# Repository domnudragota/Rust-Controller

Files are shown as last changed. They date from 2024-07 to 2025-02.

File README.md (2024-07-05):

# Project Name
GamePad/Controller
## Description

Simple GamePad built on a breadboard to test in games. Is built on Windows XInput API, so it will detect it as an XBOX Controller. The purpose of this project is (besides building a controller) to test input latency in different games and on different systems, computers and monitors in order to see the difference in input latency. Will also compare with an actual Xbox Series controller.

## Hardware

<!-- Fill out this table with all the hardware components that you mght need.

The format is 
```
| [Device](link://to/device) | This is used ... | [price](link://to/store) |

```

-->

| Device | Usage | Price |
|---|---|---|
| [Rapspberry Pi Pico W](https://www.raspberrypi.com/documentation/microcontrollers/raspberry-pi-pico.html) | The microcontroller | [35 RON](https://www.optimusdigital.ro/en/raspberry-pi-boards/12394-raspberry-pi-pico-w.html) |
| BreadBoard | Build the circuit | [10 RON] https://www.optimusdigital.ro/ro/prototipare-breadboard-uri/8-breadboard-830-points.html |
| Buttons ( 12-15 ) | Input for controller | [5 RON] https://www.optimusdigital.ro/ro/butoane-i-comutatoare/1119-buton-6x6x6.html?search_query=buton&results=222 |
| Resistances | To not fry the circuit | [5 RON] https://www.optimusdigital.ro/ro/componente-electronice-rezistoare/858-rezistor-025w-18k.html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 |
| 2x JoySticks | Move and aim with the controller | [10 RON] https://www.optimusdigital.ro/ro/senzori-senzori-de-atingere/742-modul-joystick-ps2-biaxial-negru-cu-5-pini.html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 |

## Links

<!-- Add a few links that got you the idea and that you think you will use for your project -->

1. [link](https://learn.microsoft.com/en-us/windows/win32/xinput/getting-started-with-xinput)
2. [link](https://www.howtogeek.com/792984/directinput-vs.-xinput-for-game-controllers-whats-the-difference/)
...

# Software and Code

### Rust Code for Raspberry Pi Pico W
The Rust code deployed on the Raspberry Pi Pico W reads button presses and joystick movements, packaging them into a structured format to be sent over UDP.

## Run the code
* Open the lab-main-Copy-Copy file in which IDE you desire (I used RustRover for this project)
* The code is located in /lab08/lab08_ex3_4/src/main.rs

⚠️ **Warning:** Ensure change the IP adresses and the path target to the cyw43-firmware in the code before you build it. Also the ID and the password of the network. Make sure the band of the network is 2.4GHZ!

```rust
let fw = include_bytes!("C:/Users/Andrei/Desktop/lab-main/cyw43-firmware/43439A0.bin");
let clm = include_bytes!("C:/Users/Andrei/Desktop/lab-main/cyw43-firmware/43439A0_clm.bin");

```

```rust
//change the ip adress as well

match socket
            .send_to(
                &packet,
                //here
                IpEndpoint::new(IpAddress::v4(192, 555, 553, 555), 1234), 
            )
            .await
        {
            Ok(()) => {
                info!("sent")
            }
            Err(e) => {
                warn!("send error: {:?}", e);
            }
        }
        info!("Sending packet to UDP server...");

        //match for joystick
        match socket.send_to(&packet, IpEndpoint::new
        //and here
        (IpAddress::v4(192, 555, 555, 555), 1234)).await {
            Ok(()) => info!("Joystick data sent"),
            Err(e) => warn!("send error: {:?}", e),
         }

    }
```
```rust
//change the network

const WIFI_NETWORK: &str = "da";
const WIFI_PASSWORD: &str = "da";
```

## Building the code
* Open a terminal and make sure you are in the correct directory 

⚠️ **Warning:** Please double check if the terminal correctly detects the directory (including the -Copy - Copy sufixes of the name), otherwise it won't build correctly

* To make sure you are in the correct file, use these commands

```
cd '.\lab-main - Copy - Copy\lab08\lab08_ex3_4\
```
* To build the project, simply type in the terminal
```
cargo build --release --target=thumbv6m-none-eabi  
```
* When it compiles, we need to open an UDP server so that we can send the data.
* Open the _udpserver_ file as a **separate** project/tab.
* Run the server with _cargo run_
* Once the server is fully loaded, go back to the 1st project and type in the terminal in order to flash it on the Pico

```
elf2uf2-rs -d -s ..\..\target\thumbv6m-none-eabi\release\lab08_ex3_4

```
* When the Pico connects to the UDP server, it will constantly send packets to the server
* Now we need a "translator" to decode the packets

# Detecting the Controller on Windows

## Prerequisites

Before you begin setting up the project, ensure you have the following prerequisites installed on your system:

## System Requirements
- **Operating System**: Windows 10 or newer is recommended for full compatibility.

## Software Requirements
- **.NET Framework**: .NET 5.0 or later. Make sure to download and install it from [Microsoft's official site](https://dotnet.microsoft.com/download).
- **Visual Studio** or **Visual Studio Code**: For code editing and debugging. Visual Studio can be downloaded from [here](https://visualstudio.microsoft.com/downloads/).

## Driver Installation
- **ViGEmBus Driver**: This driver is required to create a virtual Xbox controller that the system recognizes.
  - Download the latest version of the ViGEmBus driver from the [ViGEmBus GitHub releases page](https://github.com/ViGEm/ViGEmBus/releases).
  - Follow the installation instructions provided there to install the driver on your system.

## Additional Libraries
- **Nefarius.ViGEm.Client**: This is a .NET library used to interact with the ViGEmBus driver programmatically.
  - Ensure your project references this library. It can be added via NuGet in Visual Studio or by running the following command in your project directory:
    ```bash
    dotnet add package Nefarius.ViGEm.Client
    ```

## Hardware Requirements
- If testing the project physically, ensure you have a compatible hardware setup, including a game controller or custom hardware interfacing with your PC.

Make sure all prerequisites are properly installed and configured before proceeding with the project setup.

# Opening the Project and Adding NuGet Packages

## Opening the C# Project in Visual Studio

To start working on the project, you need to open it in an Integrated Development Environment (IDE). Visual Studio is recommended for C# projects. Follow these steps to open the project:

1. **Launch Visual Studio**:
   - Open Visual Studio. If you haven't installed it yet, download it from [Visual Studio Downloads](https://visualstudio.microsoft.com/downloads/).

2. **Open Project or Solution**:
- Name of the C# code is _ConsoleApp1_
   - On the initial launch screen, click **Open a project or solution**.
   - Navigate to the folder where you have cloned or downloaded the project.
   - Select the `.sln` or `.csproj` file and click **Open** to load the project into Visual Studio.

## Adding a NuGet Package

NuGet is a package manager for .NET that enables developers to share and consume useful code. Adding a NuGet package to your project can extend its functionality easily. Here's how to add a NuGet package:

1. **Open NuGet Package Manager**:
   - Right-click on the project in the **Solution Explorer** in Visual Studio.
   - Click **Manage NuGet Packages**.

2. **Browse for Packages**:
   - Go to the **Browse** tab in the NuGet Package Manager.
   - Type the package name you want to install in the search box (e.g., `Nefarius.ViGEm.Client`).

3. **Install the Package**:
   - Select the package from the list of search results.
   - Click on the **Install** button next to the package details.
   - Review any license agreements, if prompted, and accept them to proceed with the installation.

4. **Verify Package Installation**:
   - After installation, the package will appear under the **Dependencies** > **NuGet** node in your project structure.
   - You can now use the functionalities provided by the NuGet package in your project code.

## Verifying the Setup

After opening the project and adding the necessary NuGet packages, build the project to verify that everything is set up correctly:

- Click on **Build** > **Build Solution** in the menu bar.
- Ensure that the build completes without errors.

Before running the code, make sure to clode **ONLY** the UDP server in Rust, as C# will throw an exception.

# Mapping the buttons
* Run the C# code and it will display all the "translated" packages that the PICO is sending. 
## Step 1: Connect Your USB Controller

First, you need to physically connect your USB controller to your Windows machine.

- **Plug the USB connector** of your controller into a free USB port on your computer.
- Wait for Windows to recognize the device and install any necessary drivers. This process is typically automatic.

## Step 2: Check Device Recognition

After connecting your controller, verify that Windows has recognized it.

- Open **Control Panel** by typing `Control Panel` in the Start menu and pressing Enter.
- Navigate to **Hardware and Sound** > **Devices and Printers**.
- Under **Devices**, look for your USB controller. It should be listed under "Devices" if Windows recognizes it properly.
- If Device Manager can't find it, search in the Start menu for "Set Up USB Controllers".

## Step 3: Calibrate Your Controller

To ensure optimal performance, you might need to calibrate your controller. Here’s how to do it:

- Right-click on your controller icon in **Devices and Printers** and select **Game controller settings**.
- In the Game Controllers window, select your controller and click **Properties**.
- In the Properties window, go to the **Settings** tab and click on **Calibrate**.
- Follow the on-screen instructions to complete the calibration process.

## Step 4: Test Your Controller

After calibration, it’s a good idea to test the controller to make sure all buttons and joysticks are working as expected.

- In the Properties window of your controller, switch to the **Test** tab.
- Test each button and joystick on your controller. As you press buttons and move joysticks, corresponding buttons should light up in the test screen, confirming their functionality.

That's pretty much it. Let me know if there are questions regarding the compilation process.

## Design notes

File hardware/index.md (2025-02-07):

# GamePad Xinput API

A game controller coded in Rust using Xinput API

**Author**: Dragotă Andrei \
**GitHub Project Link**: https://github.com/UPB-FILS-MA/project-domnudragota

## Description

### Introduction

A rudimentary GamePad constructed on a breadboard serves as a functional prototype to test within various gaming environments. This DIY controller operates on the Windows XInput API, allowing the system to recognize it as an Xbox controller, thereby facilitating seamless integration with a wide range of games that support Xbox controller inputs. The underlying electronics and wiring are carefully assembled on a breadboard, providing a flexible platform for development and testing.

### Purpose

The primary goal of this project is to assess input latency across different gaming scenarios. By using this GamePad, which mimics the functionality of a standard Xbox controller, researchers can measure the time delay between user input and corresponding in-game actions. The experiment aims to gather data on input latency across a variety of platforms, including different operating systems, computer configurations, and monitor types. This information can help identify factors that contribute to input lag and inform hardware and software optimization strategies to improve gaming responsiveness.
Testing environment

In addition to the breadboard GamePad, an official Xbox Series controller (plus PlayStation because why not) is included for comparative analysis. By conducting parallel tests with the DIY controller and the Xbox Series controller, researchers can evaluate how closely the breadboard-built GamePad matches the performance and responsiveness of a commercially available controller. This comparative approach provides a baseline to assess whether the homemade controller exhibits any additional latency or other unexpected behavior.

### Conclusions

Basically, this project has both a technical and practical focus: it explores the construction and functionality of a custom-built controller, while simultaneously addressing broader questions related to gaming performance, user experience, and system optimization. The findings from this study could have implications for gamers, developers, and hardware manufacturers interested in minimizing input latency and enhancing gameplay fluidity.

## Motivation

As it can be probably guessed from the above paragraphs, I want to combine 2 subjects which are on opposite measurement axis (creativity and art with engineering projects). I believe that this project will help me understand how much time and effort developpers and engineers put when designing even just a little piece of the hardware part for the console or computer. Moreover, I'm keen on challenges and I wish to learn Rust as a new and innovative programming language, in comparison, I come from Java langaguage so Rust might be the perfect mix for me for C/C++ and Java. Furthermore (and last idea I promise) I want to create a small presentation involving statistics and measuring data to show that projects can be done in an equal rhythm with fun, creativity and hard work.

## Architecture 

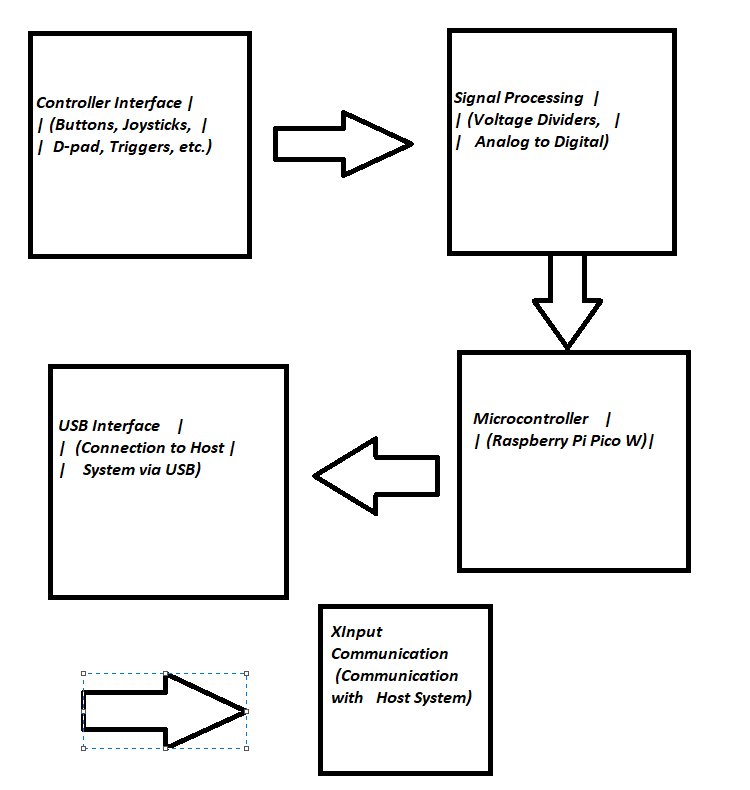
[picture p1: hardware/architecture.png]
architecture


Here is a small diagram of all the connections (I think) should be neccessary for the controller. I'll also try to describe it in words. Hopefully it will make sense.

### Main Components

Controller Interface->
This is the collection of user input elements, including buttons, joysticks, and directional pads. It's what the user interacts with to control the game.

Signal Processing->
This component receives input signals from the controller interface and translates them into data that the microcontroller can process. In this case, it includes the voltage dividers for button groupings.

Microcontroller->
The central component responsible for processing input data, managing the XInput API communication, and handling USB communication. The Raspberry Pi Pico W is used for this project.

USB Interface->
This is the connection point between the microcontroller and the host system (e.g., a Windows computer). It allows the controller to be recognized as an XInput device.

XInput Communication->
This component encapsulates the interaction between the microcontroller and the host system through the XInput API. It translates input signals into a format that games can understand.

### Connections

Controller Interface to Signal Processing->
The input components (buttons, joysticks, etc.) are connected to the signal processing unit. Voltage dividers are used to group certain buttons, reducing the number of required digital pins.

Signal Processing to Microcontroller->
The processed signals are sent to the microcontroller for further handling. The microcontroller is responsible for interpreting the inputs and sending appropriate responses to the host system.

Microcontroller to USB Interface->
The microcontroller connects to the USB interface, which allows it to communicate with the host system. This connection enables the controller to be recognized as an XInput device.

Microcontroller to XInput Communication ->
The microcontroller sends input data to the host system using the XInput API. This component ensures that the controller's input is properly formatted and recognized by compatible games.

## Log

<!-- write every week your progress here -->

### Week 6 - 12 May
Designed the hardware on the breadboard, applied the voltage dividers to the circuit, finished up the KiCad hardware schematic
### Week 7 - 19 May
Finished up the hardware on the breadboard + final version on KiCad. Should start with software now.
### Week 20 - 26 May
Software is finished. Windows detects the Pico W as a generic xbox 360 controller and responds to inputs. Code is in project repo.
## Hardware

The controller has 16 buttons, 2 vibration motors, 2 joysticks, resistances of 220 ohms to not blow up the circuit. Pico will process all the inputs from the buttons and will translate it for the XInput app. 

To implement the project, you need a board with a native USB port, such as the Raspberry Pi Pico.

I chose to use two voltage dividers to save the digital pins on the board. The directional buttons and the A/B/X/Y buttons are grouped by 4 in a voltage divider.

The disadvantage of these groupings is that two or more buttons from the same group cannot be read simultaneously. For example, pressing buttons A and B at the same time will send to the analog pin the value corresponding to pressing button B, not both. (fixed it, should work)

Another compromise is the fact that, for reasons of availability, the "Trigger" buttons are not analog. The value sent to the XInput API is either 0% pressed or 100% pressed.

### Schematics

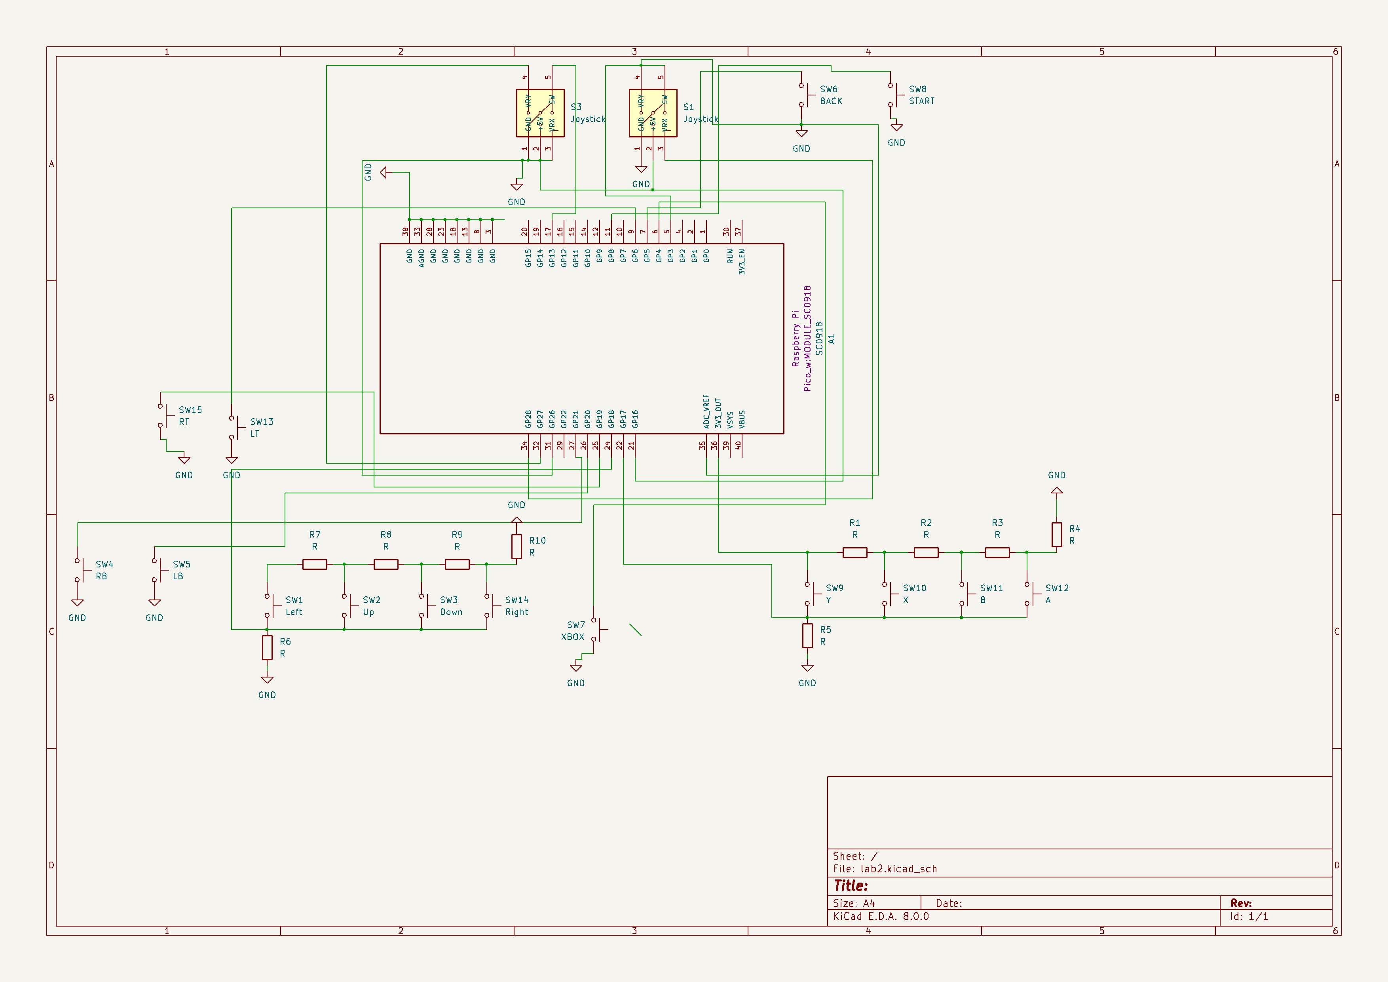
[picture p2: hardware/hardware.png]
hardware


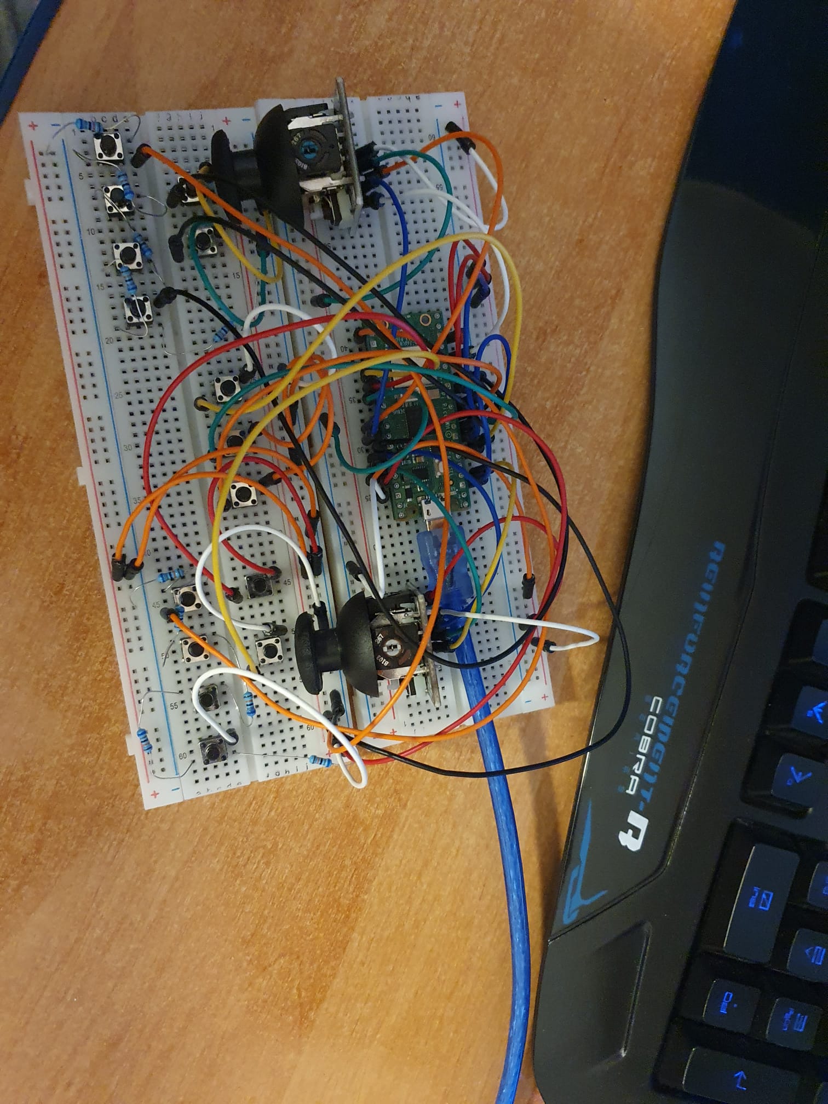
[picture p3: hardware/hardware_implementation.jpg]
hardware_implementation


### Bill of Materials

<!-- Fill out this table with all the hardware components that you might need.

The format is 
```
| [Device](link://to/device) | This is used ... | [price](link://to/store) |

```

-->

| Device | Usage | Price |
|---|---|---|
| [Rapspberry Pi Pico W](https://www.raspberrypi.com/documentation/microcontrollers/raspberry-pi-pico.html) | The microcontroller | [35 RON](https://www.optimusdigital.ro/en/raspberry-pi-boards/12394-raspberry-pi-pico-w.html) |
| 2 x BreadBoard| Build the circuit | [20 RON](https://www.optimusdigital.ro/ro/prototipare-breadboard-uri/8-breadboard-830-points.html) |
| Buttons ( 12-15 ) | Input for controller | [5 RON](https://www.optimusdigital.ro/ro/butoane-i-comutatoare/1119-buton-6x6x6.html?search_query=buton&results=222) |
| Resistances | To not fry the circuit | [5 RON](https://www.optimusdigital.ro/ro/componente-electronice-rezistoare/858-rezistor-025w-18k.html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) |
| 2x JoySticks | Move and aim with the controller | [10 RON](https://www.optimusdigital.ro/ro/senzori-senzori-de-atingere/742-modul-joystick-ps2-biaxial-negru-cu-5-pini.html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) |

## Software

| Library | Description | Usage |
|---|---|---|
| [rusty_xinput](https://docs.rs/rusty-xinput/latest/rusty_xinput/#) | Crate for Rust | Implements Xinput .dll in Rust, has several functions |
| [gilrs](https://docs.rs/gilrs/latest/gilrs/) | GilRs - Game Input Library for Rust | GilRs abstract platform specific APIs to provide unified interfaces for working with gamepads |
| [Xinput](https://learn.microsoft.com/en-us/windows/win32/xinput/xinput-game-controller-apis-portal) | Bread and butter of this project (main driver) | Xinput, comes with Windows |
| [embassy_rs](https://github.com/embassy-rs/embassy) | Embassy framework for embedded systems| Implement specifically USB module, ADC converter, UDP Wi-fi |
## Links

<!-- Add a few links that inspired you and that you think you will use for your project -->

1. [Microsoft Official Doc](https://learn.microsoft.com/en-us/windows/win32/xinput/getting-started-with-xinput)
2. [Implementation example](https://dev.to/jeikabu/gamepad-input-with-rust-2oji)
3. [Sketch of a controller using spare parts](https://www.youtube.com/watch?v=YEDTK_Yv0vo)

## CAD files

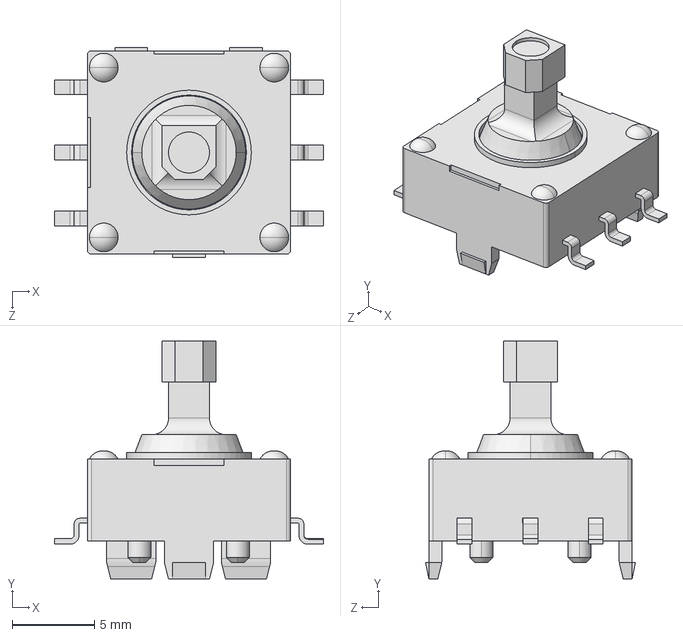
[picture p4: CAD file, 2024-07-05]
joystick_symbol/JS5208/JS5208.step
16.4 x 14.5 x 12.8 mm

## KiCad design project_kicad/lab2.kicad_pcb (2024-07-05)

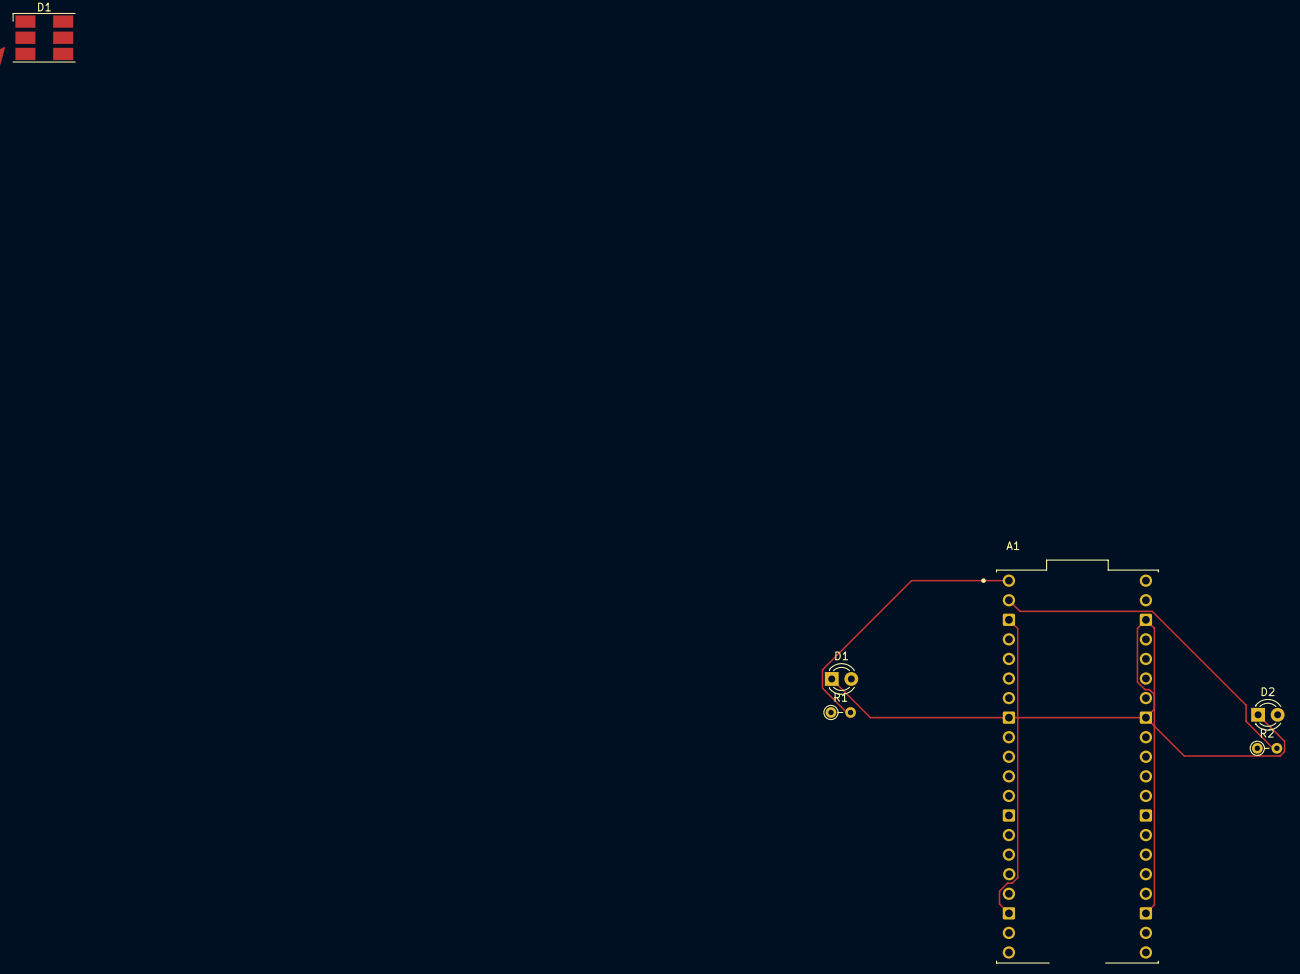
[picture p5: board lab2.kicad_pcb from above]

Board: 2 copper layers, 7 parts (0 on the bottom side), 5 nets.

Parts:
A1: SC0918; MODULE_SC0918
D1, D2: LED; LED_D3.0mm
D1#2: LED_ARGB; LED_RGB_Cree-PLCC-6_6x5mm_P2.1mm
R1, R2: R; R_Axial_DIN0204_L3.6mm_D1.6mm_P2.54mm_Vertical
RN1: VoltageDivider; Symbol_HighVoltage_NoTriangle_6x15mm_Copper

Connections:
GND: A1.3 (GND), A1.8 (GND), A1.13 (GND), A1.18 (GND), A1.23 (GND), A1.28 (GND), A1.33 (AGND), A1.38 (GND), D1.1 (K), D2.1 (K)
unnamed: A1.2 (GP1), D1#2.1 (A)
unnamed: A1.4 (GP2), R2.2
unnamed: D1.2 (A), R1.1
unnamed: D2.2 (A), R2.1

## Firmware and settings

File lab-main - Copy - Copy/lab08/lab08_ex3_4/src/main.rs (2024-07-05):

#![no_std]
#![no_main]

use core::panic::PanicInfo;
use core::str::from_utf8;

use byte_slice_cast::AsByteSlice;
use cyw43_pio::PioSpi;
use embassy_executor::Spawner;
use embassy_futures::select;
use embassy_net::tcp::TcpSocket;
use embassy_net::udp::{PacketMetadata, UdpSocket};
use embassy_net::{Config, IpAddress, IpEndpoint, Ipv4Address, Ipv4Cidr, Stack, StackResources};
use embassy_rp::bind_interrupts;
use embassy_rp::gpio::{Input, Level, Output, Pull};
use embassy_rp::peripherals::{DMA_CH0, PIO0};
use embassy_rp::pio::{InterruptHandler, Pio};
use embassy_time::{Duration, Timer};
use embedded_io_async::Write;
use heapless::Vec;
use log::{info, warn};
use static_cell::StaticCell;
use embassy_rp::adc::{Adc, Channel, Config as AdcConfig, InterruptHandler as AdcInterruptHandler};


// USB driver
use embassy_rp::peripherals::USB;
use embassy_rp::usb::{Driver, Endpoint, InterruptHandler as USBInterruptHandler};

bind_interrupts!(struct Irqs {
    USBCTRL_IRQ => USBInterruptHandler<USB>;
    ADC_IRQ_FIFO => AdcInterruptHandler;
    PIO0_IRQ_0 => InterruptHandler<PIO0>;
});

const WIFI_NETWORK: &str = "dragota_a";
const WIFI_PASSWORD: &str = "sygd6347";

#[embassy_executor::task]
async fn logger_task(driver: Driver<'static, USB>) {
    embassy_usb_logger::run!(1024, log::LevelFilter::Info, driver);
}

#[embassy_executor::task]
async fn wifi_task(
    runner: cyw43::Runner<'static, Output<'static>, PioSpi<'static, PIO0, 0, DMA_CH0>>,
) -> ! {
    runner.run().await
}

#[embassy_executor::task]
async fn net_task(stack: &'static Stack<cyw43::NetDriver<'static>>) -> ! {
    stack.run().await
}

#[embassy_executor::main]
async fn main(spawner: Spawner) {
    let peripherals = embassy_rp::init(Default::default());
    let mut adc = Adc::new(peripherals.ADC, Irqs, AdcConfig::default());
    // Start the USB logger driver
    let driver = Driver::new(peripherals.USB, Irqs);
    spawner.spawn(logger_task(driver)).unwrap();

    let mut button_a = Input::new(peripherals.PIN_6, Pull::Up); //xbox
    let mut button_lt =  Input::new(peripherals.PIN_9, Pull::Up); // LT
    let mut button_rt = Input::new(peripherals.PIN_10, Pull::Up); // RT
    let mut button_lb = Input::new(peripherals.PIN_26, Pull::Up); // LB
    let mut button_rb = Input::new(peripherals.PIN_27, Pull::Up); // RB
    let mut button_back = Input::new(peripherals.PIN_7, Pull::Up); // BACK
    let mut start = Input::new(peripherals.PIN_11, Pull::Up); // START
    let mut button_abxy = Input::new(peripherals.PIN_22, Pull::Up); // ABXY
    let mut button_udlr = Input::new(peripherals.PIN_14, Pull::Up); // UPDOWNLEFTRIGHT


    //JOSYSTICKS

    struct Joystick {
        lx: i16,
        ly: i16,
        rx: i16,
        ry: i16,
     }

     let mut joystick1 = Joystick { lx: 0, ly: 0, rx: 0, ry: 0 };
     let mut joystick2 = Joystick { lx: 0, ly: 0, rx: 0, ry: 0 };

//dont work but this is how i would have implemented it with adc
//     let joystick1 = Joystick {
//         lx_channel: adc.bind_channel(peripherals.GPIO26),
//         ly_channel: adc.bind_channel(peripherals.GPIO27),
//         rx_channel: adc.bind_channel(peripherals.GPIO28),
//         ry_channel: adc.bind_channel(peripherals.GPIO29),
//     };
 async fn update_joystick1(joystick: &mut Joystick) {
         joystick.lx = (joystick.lx + 100).clamp(-32768, 32767);
        joystick.ly = (joystick.ly + 100).clamp(-18976, 18976);
        joystick.rx = (joystick.rx - 100).clamp(-32768, 32767);
       joystick.ry = (joystick.ry - 100).clamp(-18976, 18976);
    }

    async fn update_joystick2(joystick: &mut Joystick) {
         joystick.lx = (joystick.lx + 100).clamp(-32768, 32767);
         joystick.ly = (joystick.ly + 100).clamp(-18976, 18976);
         joystick.rx = (joystick.rx - 100).clamp(-32768, 32767);
         joystick.ry = (joystick.ry - 100).clamp(-18976, 18976);
     }

    // async fn update_joystick(joystick: &mut Joystick, adc: &mut Adc) {
    //     let lx = adc.read(joystick.lx_channel).await.unwrap_or_default();
    //     let ly = adc.read(joystick.ly_channel).await.unwrap_or_default();
    //     let rx = adc.read(joystick.rx_channel).await.unwrap_or_default();
    //     let ry = adc.read(joystick.ry_channel).await.unwrap_or_default();
    //
    //     // Convert ADC reading (0-4095) to joystick range (-32768 to 32767)
    //     joystick.lx = ((lx as i32 * 65535 / 4095) - 32768).clamp(-32768, 32767);
    //     joystick.ly = ((ly as i32 * 65535 / 4095) - 32768).clamp(-32768, 32767);
    //     joystick.rx = ((rx as i32 * 65535 / 4095) - 32768).clamp(-32768, 32767);
    //     joystick.ry = ((ry as i32 * 65535 / 4095) - 32768).clamp(-32768, 32767);
    // }





    let fw = include_bytes!("C:/Users/Andrei/Desktop/lab-main/cyw43-firmware/43439A0.bin");
    let clm = include_bytes!("C:/Users/Andrei/Desktop/lab-main/cyw43-firmware/43439A0_clm.bin");


    let pwr = Output::new(peripherals.PIN_23, Level::Low);
    let cs = Output::new(peripherals.PIN_25, Level::High);
    let mut pio = Pio::new(peripherals.PIO0, Irqs);
    let spi = PioSpi::new(
        &mut pio.common,
        pio.sm0,
        pio.irq0,
        cs,
        peripherals.PIN_24,
        peripherals.PIN_29,
        peripherals.DMA_CH0,
    );


    static STATE: StaticCell<cyw43::State> = StaticCell::new();
    let state = STATE.init(cyw43::State::new());
    let (net_device, mut control, runner) = cyw43::new(state, pwr, spi, fw).await;
    spawner.spawn(wifi_task(runner)).unwrap();


    control.init(clm).await;
    control
        .set_power_management(cyw43::PowerManagementMode::PowerSave)
        .await;

    let config = Config::dhcpv4(Default::default());


    let seed = 0x0123_4567_89ab_cdef;


    static STACK: StaticCell<Stack<cyw43::NetDriver<'static>>> = StaticCell::new();
    static RESOURCES: StaticCell<StackResources<2>> = StaticCell::new();
    let stack = &*STACK.init(Stack::new(
        net_device,
        config,
        RESOURCES.init(StackResources::<2>::new()),
        seed,
    ));


    spawner.spawn(net_task(stack)).unwrap();

    loop {


        match control.join_wpa2(WIFI_NETWORK, WIFI_PASSWORD).await {
            Ok(_) => break,
            Err(err) => {
                info!("join failed with status {}", err.status);
            }
        }
    }

    // Wait for DHCP (not necessary when using static IP)
    info!("waiting for DHCP...");
    while !stack.is_config_up() {
        Timer::after_millis(100).await;
    }
    info!("DHCP is now up {:?}!", stack.config_v4());

    // And now we can use it!

    // TODO 1: Create buffers
    let mut rx_buffer = [0; 4096];
    let mut rx_metadata_buffer = [PacketMetadata::EMPTY; 3];
    let mut tx_buffer = [0; 4096];
    let mut tx_metadata_buffer = [PacketMetadata::EMPTY; 3];

    let mut buf = [0u8; 4096];

    // TODO 2: Initialize UDP socket
    let mut socket = UdpSocket::new(
        stack,
        &mut rx_metadata_buffer,
        &mut rx_buffer,
        &mut tx_metadata_buffer,
        &mut tx_buffer,
    );



    info!("Starting server on UDP:1234...");


    if let Err(e) = socket.bind(1234) {
        warn!("accept error: {:?}", e);
        return;
    }

    loop {




        let mut packet = [0u8; 30];

        packet[0] = button_a.is_low().into();
        packet[1] = button_lt.is_low().into();
        packet[2] = button_rt.is_low().into();
        packet[3] = button_lb.is_low().into();
        packet[4] = button_rb.is_low().into();
        packet[5] = button_back.is_low().into();
        packet[6] = start.is_low().into();
        packet[7] = button_abxy.is_low().into();
        packet[8] = button_udlr.is_low().into();

        //joystick data

        packet[9..11].clone_from_slice(&joystick1.lx.to_ne_bytes());
        packet[11..13].clone_from_slice(&joystick1.ly.to_ne_bytes());
        packet[13..15].clone_from_slice(&joystick1.rx.to_ne_bytes());
        packet[15..17].clone_from_slice(&joystick1.ry.to_ne_bytes());

        packet[19..21].clone_from_slice(&joystick2.lx.to_ne_bytes());
        packet[21..23].clone_from_slice(&joystick2.ly.to_ne_bytes());
        packet[23..25].clone_from_slice(&joystick2.rx.to_ne_bytes());
        packet[25..27].clone_from_slice(&joystick2.ry.to_ne_bytes());

         update_joystick1(&mut joystick1).await;
         update_joystick2(&mut joystick2).await;


        control.gpio_set(0, true).await;

        match socket
            .send_to(
                &packet,
                IpEndpoint::new(IpAddress::v4(192, 168, 243, 162), 1234), //dynamic, always change it
            )
            .await
        {
            Ok(()) => {
                info!("sent")
            }
            Err(e) => {
                warn!("send error: {:?}", e);
            }
        }
        info!("Sending packet to UDP server...");

        //match for joystick
        match socket.send_to(&packet, IpEndpoint::new(IpAddress::v4(192, 168, 243, 162), 1234)).await {
            Ok(()) => info!("Joystick data sent"),
            Err(e) => warn!("send error: {:?}", e),
         }

    }

}

#[panic_handler]
fn panic(info: &PanicInfo) -> ! {
    if let Some(location) = info.location() {
        info!("panic occurred in file '{}' at line {}", location.file(), location.line());
    } else {
        info!("panic occurred but can't get location information...");
    }
    if let Some(s) = info.payload().downcast_ref::<&str>() {
        info!("panic payload: {}", s);
    }
    loop {}
}

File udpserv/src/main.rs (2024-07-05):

use tokio::net::UdpSocket;
use std::{io, str::from_utf8};

#[tokio::main]
async fn main() -> io::Result<()> {
    let sock = UdpSocket::bind("0.0.0.0:1234").await?;  // Listen on all interfaces at port 1234
    let mut buf = [0; 1024];  // Buffer to hold incoming data

    loop {
        let (len, addr) = sock.recv_from(&mut buf).await?;  // Receive data into the buffer
        println!("Received from {:?}", addr);  // Log the source address

        // Ensure there is enough data to read joystick values
        if len >= 17 {  // Check if the buffer has enough bytes to read data for two joysticks
            // Decode joystick data for the first joystick
            let lx1 = i16::from_ne_bytes([buf[9], buf[10]]);
            let ly1 = i16::from_ne_bytes([buf[11], buf[12]]);
            println!("Joystick 1 - LX: {}, LY: {}", lx1, ly1);

            // Decode joystick data for the second joystick
            let lx2 = i16::from_ne_bytes([buf[13], buf[14]]);
            let ly2 = i16::from_ne_bytes([buf[15], buf[16]]);
            println!("Joystick 2 - LX: {}, LY: {}", lx2, ly2);
        }
    }
}
